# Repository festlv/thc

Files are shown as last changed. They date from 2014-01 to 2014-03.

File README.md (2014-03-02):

Homebrew plasma cutter torch height controller
--------------------------------------------------

Schematics, layout and code for a simple yet intelligent replacement for THC301d
torch height controller.

The main difference is that this one samples cutting voltage automatically
after cut is started, and then tries to keep the plasma torch at the same
height.

Beware- this has only been tested for a few hours as of now, but the results
seem to be as good as with THC301d (but setpoint is determined automatically).

License: GNU General Public License (GPL) version 3.

Author: Reinis Veips, http://wot.lv/

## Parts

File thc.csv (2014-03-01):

ref | value | footprint
C1 | 0.1uF | ~
C2 | 1uF | ~
C3 | 1uF | ~
C4 | 100uF | ~
C5 | 1uF | ~
C6 | 10uF | ~
C7 | 10uF | ~
C8 | 0.1uF | ~
C9 | 10uF | ~
C10 | 0.1uF | ~
C11 | 0.1uF | ~
C12 | 10uF | ~
CON1 | BARREL_JACK | ~
D1 | 5v1 ZENER | ~
D2 | 1N4007 | ~
D3 | 5v1 ZENER | ~
D4 | 5v1 ZENER | ~
D5 | 5v1 ZENER | ~
D6 | 5v1 ZENER | ~
D7 | 5v1 ZENER | ~
D8 | 5v1 ZENER | ~
D9 | 5v1 ZENER | ~
D10 | 5v1 ZENER | ~
D11 | 12v1 ZENER | ~
D12 | 12v1 ZENER | ~
F1 | PTC 1.1A 30V | ~
IC1 | 4N25 | DIP6
IC2 | 4N25 | DIP6
IC3 | 4N25 | DIP6
J2 | DB25 | ~
J3 | DB9 | ~
PH1 | IL300 | ~
Q1 | BC547 | TO92
R1 | 10K | ~
R2 | 10K | ~
R3 | 100R | ~
R4 | 10K | ~
R5 | 10K | ~
R6 | 10K | ~
R7 | 200R | ~
R8 | 200R | ~
R9 | 200R | ~
R10 | 200R | ~
R11 | 200R | ~
R12 | 200R | ~
R13 | 200R | ~
R14 | 200R | ~
R15 | 200R | ~
R16 | 10K | ~
R17 | 10K | ~
R18 | 10K | ~
R19 | 10K | ~
R20 | 100R | ~
R21 | 3K3 | ~
R22 | 47k | ~
R23 | 10K | ~
R24 | 400R | ~
R25 | 230R | ~
R26 | 400R | ~
R27 | 1K | ~
R28 | 1K | ~
R29 | 47k | ~
U1 | LM358
U2 | ARDUINO_MINI_PRO | ~
U3 | CNY74-4
U4 | 7805 | ~
U5 | ISOL_PWR
U6 | 74HC04 | ~
U7 | CNY74-4
U8 | ISOL_PWR | ~
U9 | LM358

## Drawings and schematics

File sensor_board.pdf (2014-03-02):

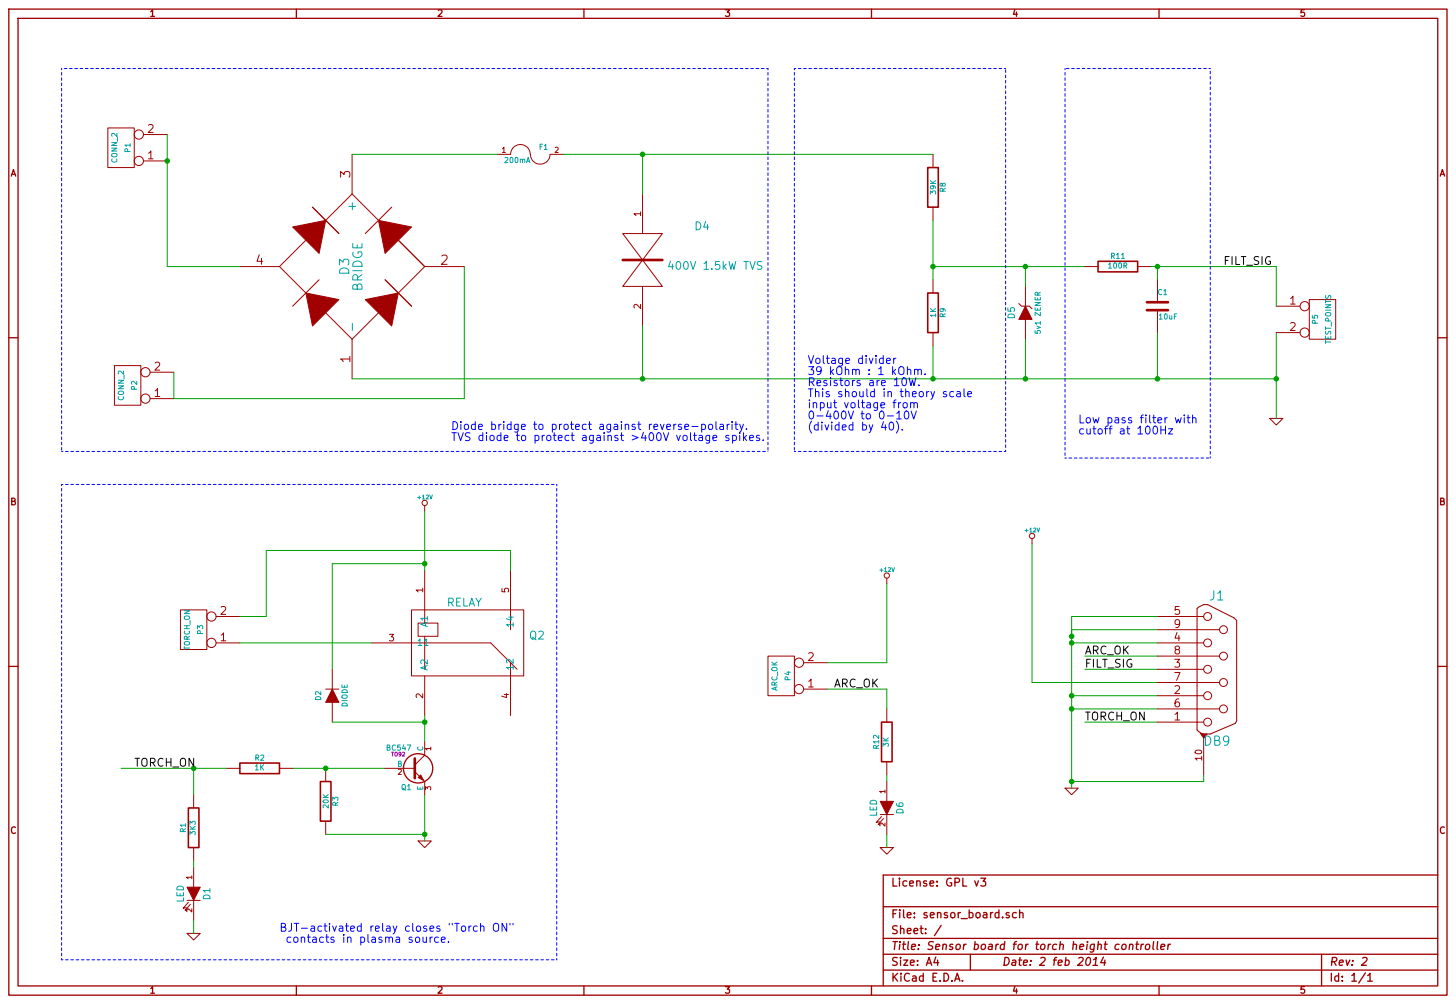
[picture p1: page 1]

Voltage divider
39 kOhm : 1 kOhm. Resistors are 10W. This should in theory scale

cutoff at 100Hz BJT-activated relay closes "Torch ON"

Diode bridge to protect against reverse-polarity.

FILT_SIG | 9 10 3

ARC_OK | 8

File: sensor_board.sch
Sheet: /
Title: Sensor board for torch height controller

contacts in plasma source.

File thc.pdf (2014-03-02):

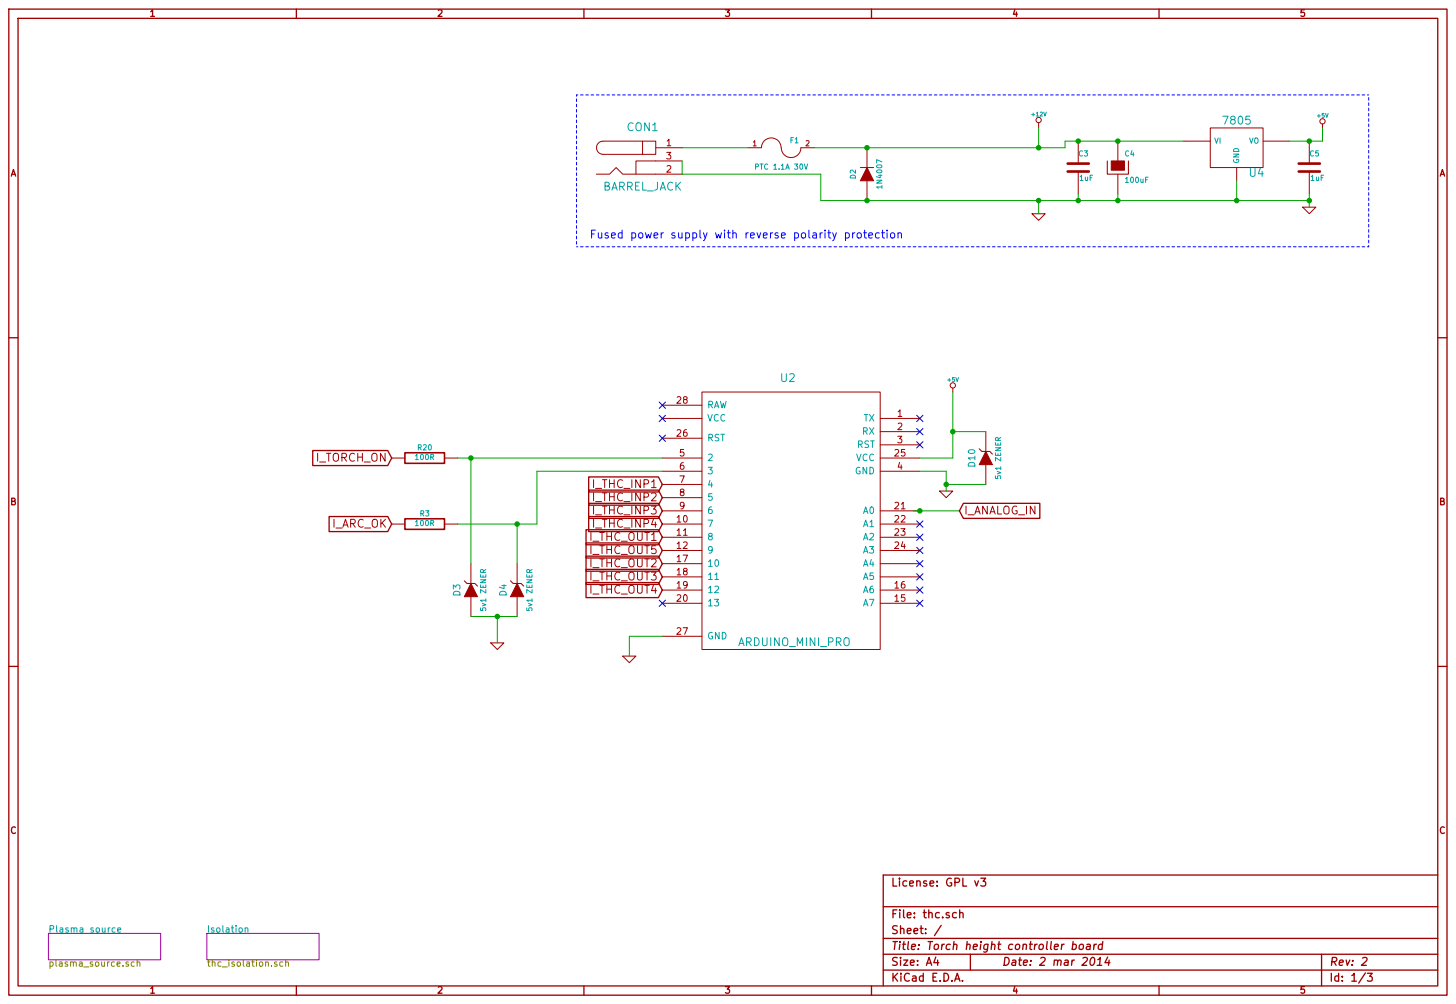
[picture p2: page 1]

Title: Torch height controller board File: thc.sch Sheet: /

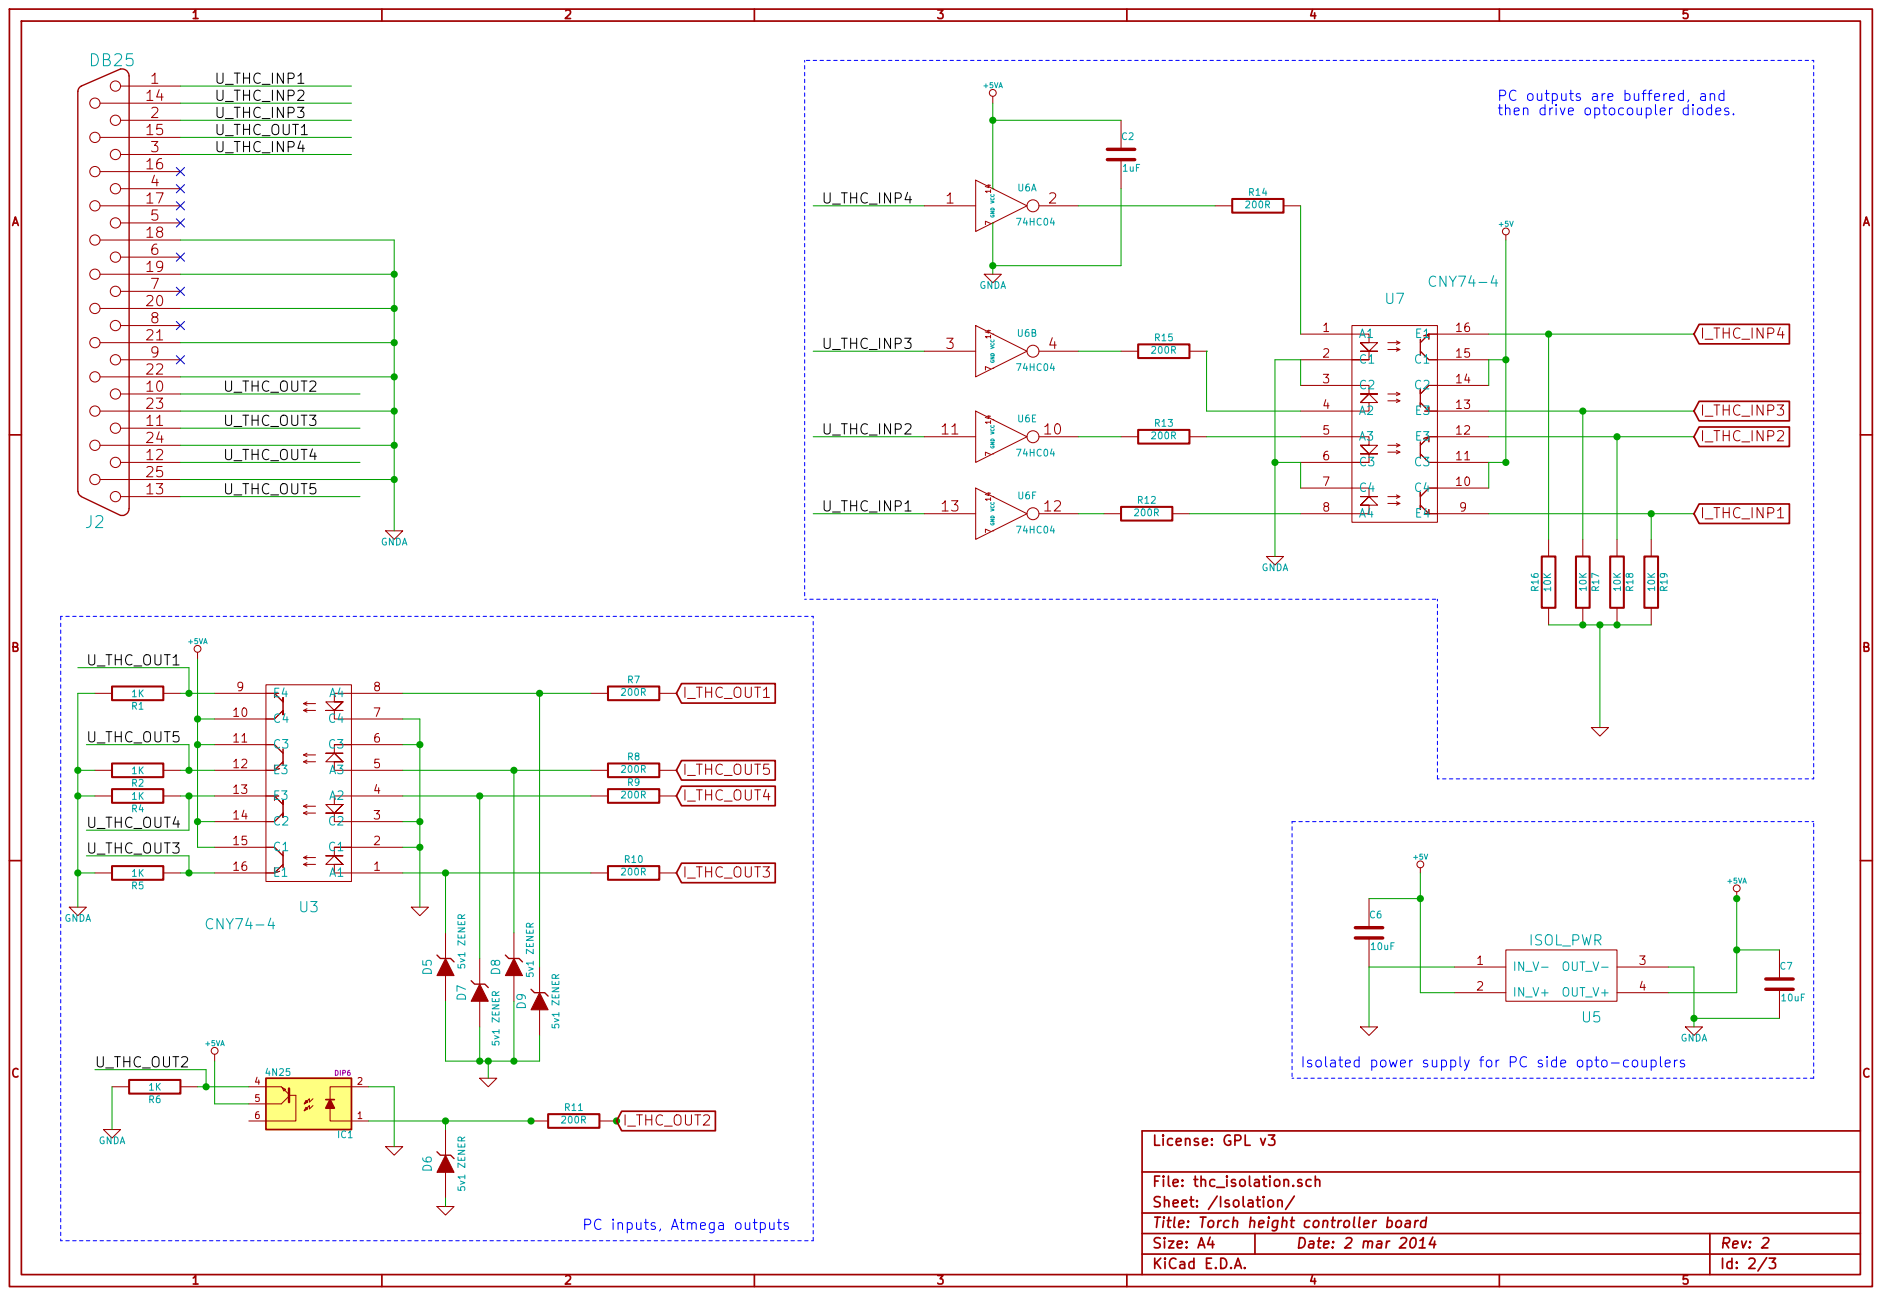
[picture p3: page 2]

PC outputs are buffered, and
then drive optocoupler diodes.

Isolated power supply for PC side opto-couplers

File: thc_isolation.sch
Sheet: /Isolation/
Title: Torch height controller board

PC inputs, Atmega outputs

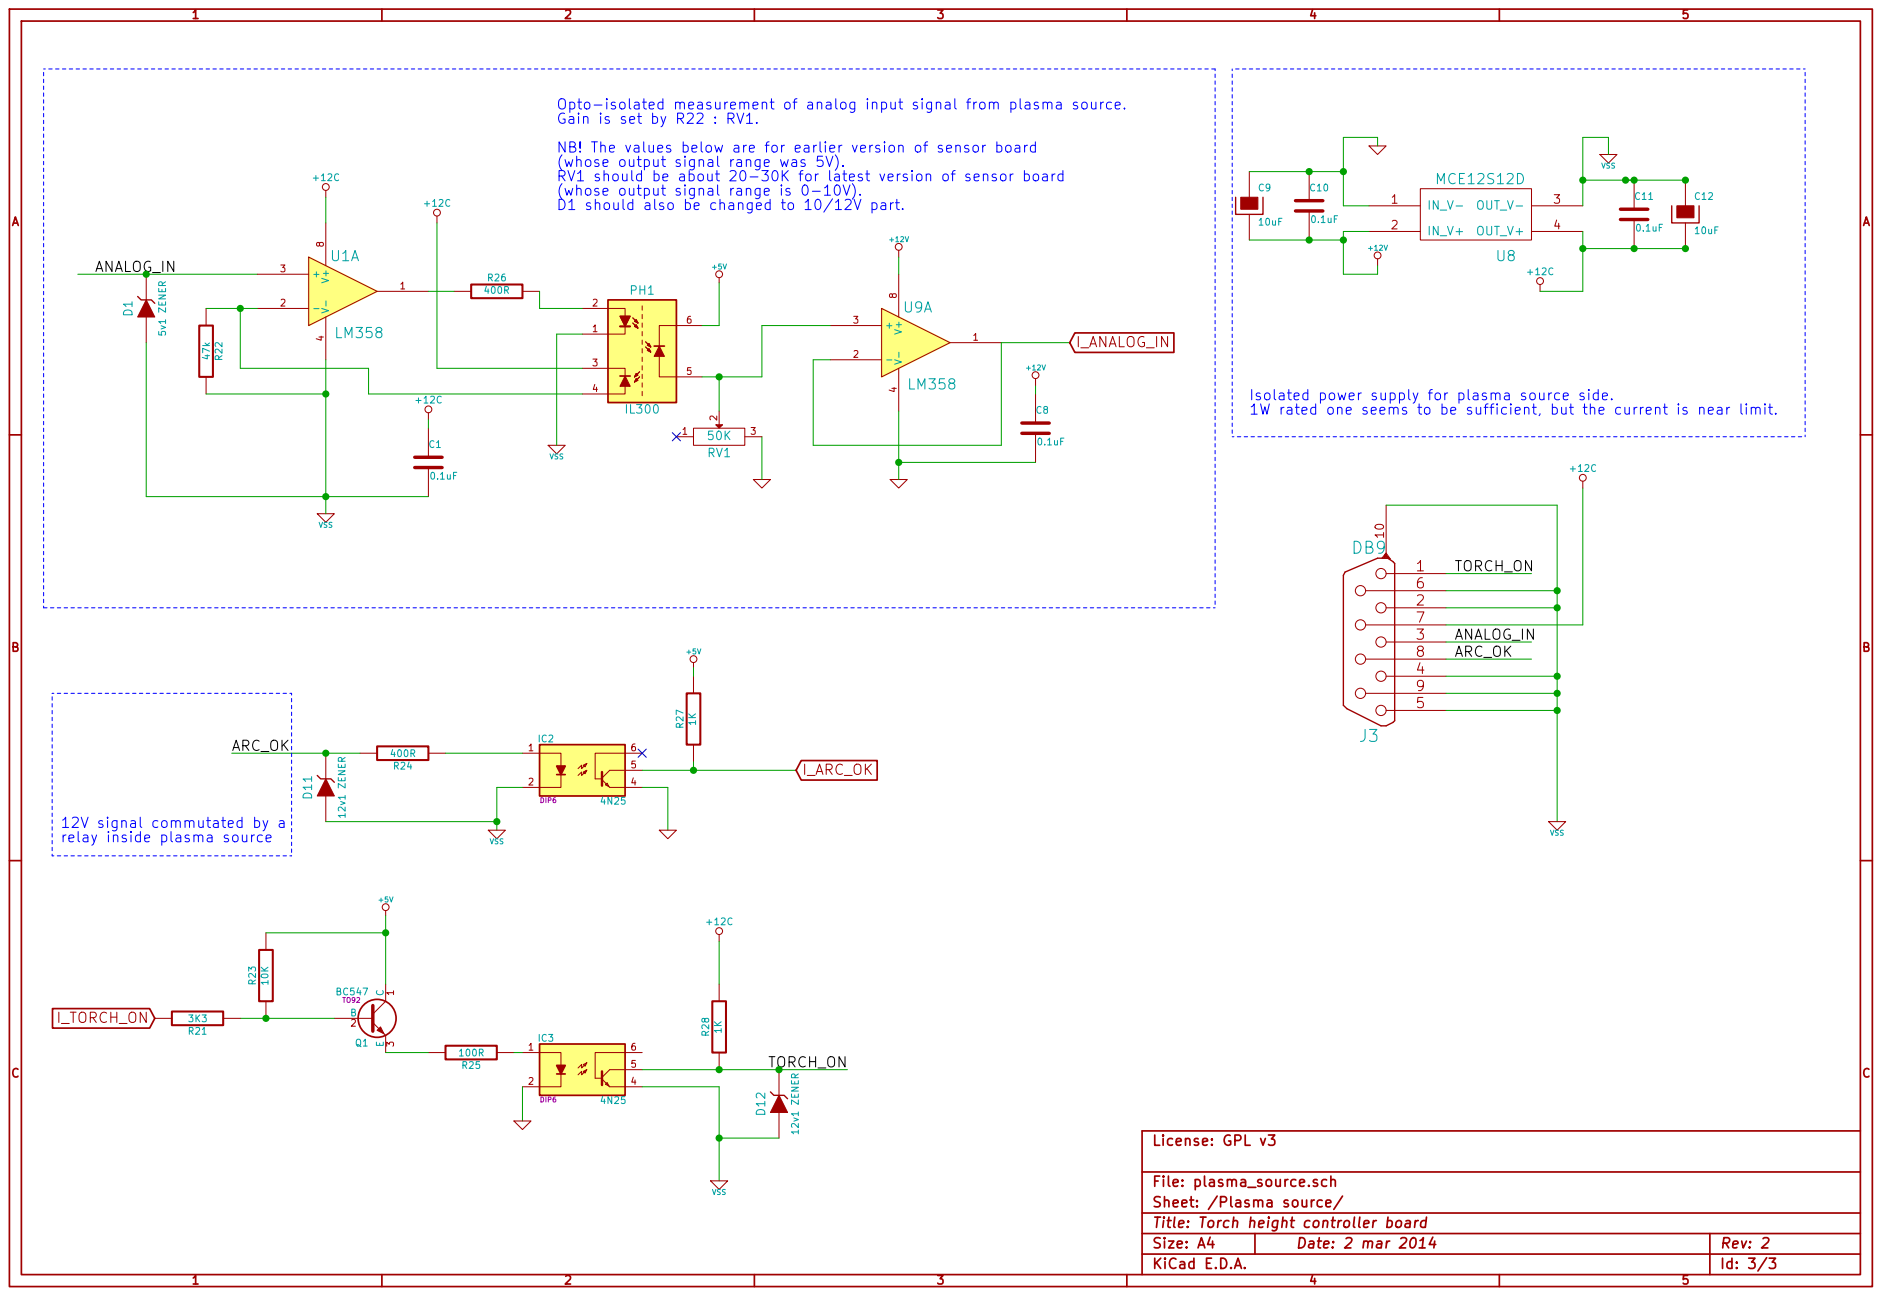
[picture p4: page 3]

50K Opto-isolated measurement of analog input signal from plasma source.
Gain is set by R22 : RV1. NB! The values below are for earlier version of sensor board (whose output signal range was 5V). RV1 should be about 20-30K for latest version of sensor board

(whose output signal range is 0-10V).
D1 should also be changed to 10/12V part.

Isolated power supply for plasma source side.
1W rated one seems to be sufficient, but the current is near limit.

12V signal commutated by a
relay inside plasma source

File: plasma_source.sch
Sheet: /Plasma source/
Title: Torch height controller board

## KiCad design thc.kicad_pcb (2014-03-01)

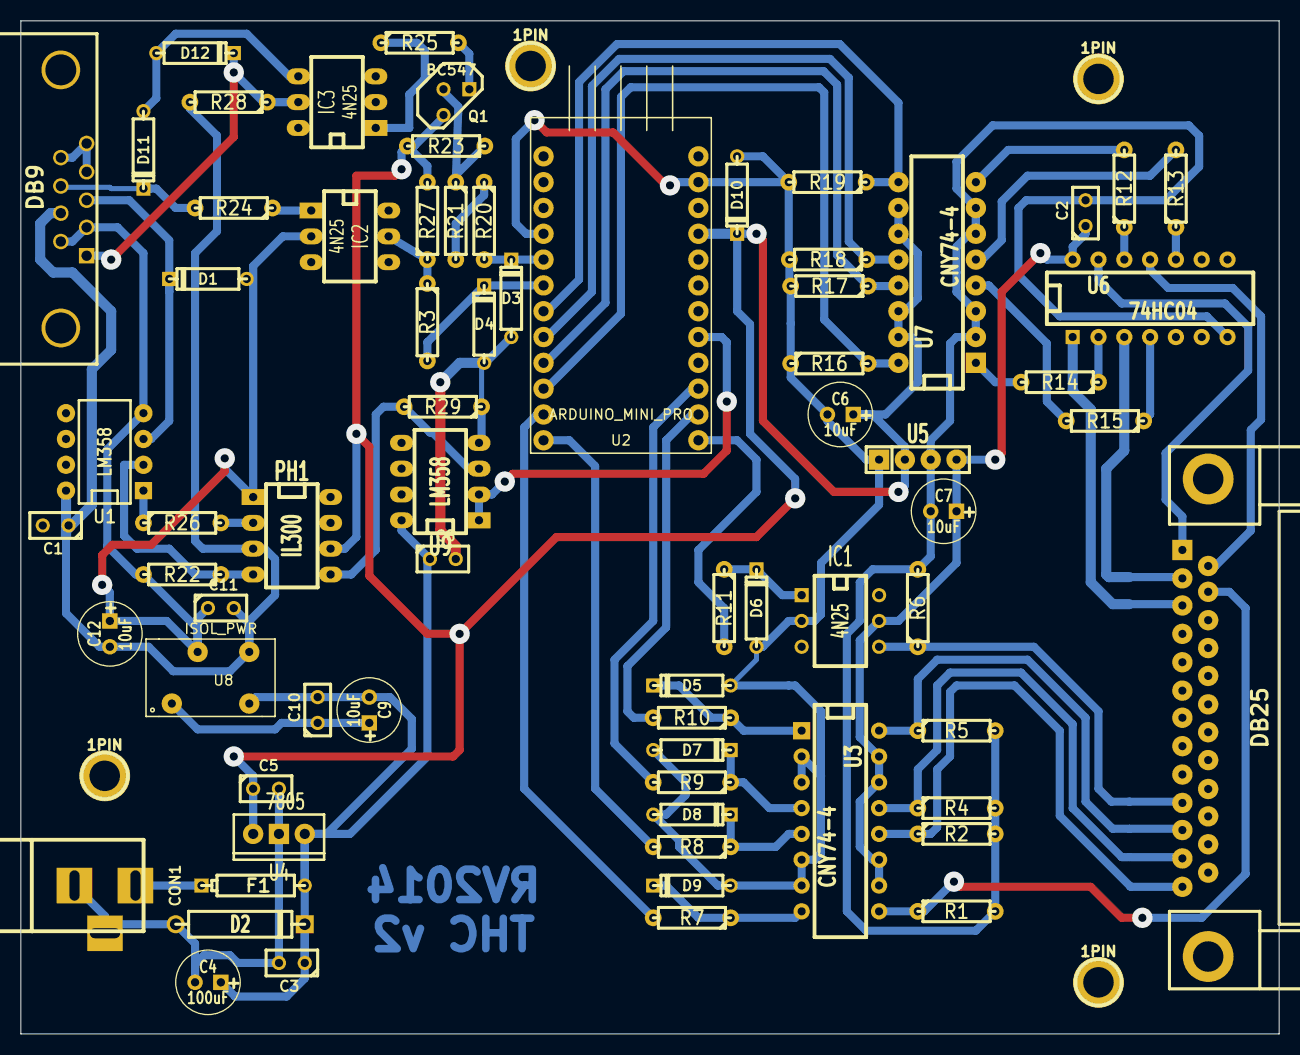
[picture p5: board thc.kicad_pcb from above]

Board: 2 copper layers, 123.8 x 99.7 mm, 75 parts (0 on the bottom side), 55 nets.

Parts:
1PIN, 1PIN#2, 1PIN#3, 1PIN#4: P***; 1pin
C1, C8, C10, C11: 0.1uF; C1
C2, C3, C5: 1uF; C1
C4: 100uF; C1V7
C6, C7, C9, C12: 10uF; C1V7
CON1: BARREL_JACK
D1, D3, D4, D5, D6, D7, D8, D9, D10: 5v1 ZENER; D3
D2: 1N4007; D5
D11, D12: 12v1 ZENER; D3
F1: PTC 1.1A 30V; CP4
IC1: 4N25; DIP-6__300
IC2, IC3: 4N25; DIP-6__300_ELL
J2: DB25; DB25FC
J3: DB9; DB9FC
PH1: IL300; DIP-8__300_ELL
Q1: BC547; TO92-EBC
R1, R2, R4, R5, R6, R16, R17, R18, R19, R23: 10K; R3-LARGE_PADS
R3, R20, R25: 100R; R3-LARGE_PADS
R7, R8, R9, R10, R11, R12, R13, R14, R15: 200R; R3-LARGE_PADS
R21: 3K3; R3-LARGE_PADS
R22, R29: 47k; R3-LARGE_PADS
R24, R26: 400R; R3-LARGE_PADS
R27, R28: 1K; R3-LARGE_PADS
U1: LM358; DIP-8__300
U2: ARDUINO_MINI_PRO; ARDUINO_MINI
U3, U7: CNY74-4; DIP-16__300
U4: 7805; LM78XXV
U5: ISOL_PWR; SIL-4
U6: 74HC04; DIP-14__300
U8: ISOL_PWR; MCE_DIP
U9: LM358; DIP-8__300_ELL

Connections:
+5V: C5.1, C6.1, D10.2, PH1.6, Q1.1, R23.2, R27.2, U2.25, U4.VO, U5.2, U7.10, U7.11, U7.14, U7.15
+5VA: C2.1, C7.1, IC1.5, U3.10, U3.11, U3.14, U3.15, U5.4, U6.14
+12C: C1.1, C11.2, C12.2, J3.7, PH1.3, R28.2, U1.8, U8.4
+12V: C3.1, C4.1, C8.1, C9.2, C10.2, D2.2, F1.2, U4.VI, U8.2, U9.8
/Isolation/U_THC_INP1: J2.1, U6.13
/Isolation/U_THC_INP2: J2.14, U6.11
/Isolation/U_THC_INP3: J2.2, U6.3
/Isolation/U_THC_INP4: J2.3, U6.1
/Isolation/U_THC_OUT1: J2.15, R1.1, U3.9
/Isolation/U_THC_OUT2: IC1.4, J2.10, R6.1
/Isolation/U_THC_OUT3: J2.11, R5.1, U3.16
/Isolation/U_THC_OUT4: J2.12, R4.1, U3.13
/Isolation/U_THC_OUT5: J2.13, R2.1, U3.12
/Plasma source/ANALOG_IN: D1.2, J3.3, U1.3
/Plasma source/ARC_OK: D11.2, J3.8, R24.2
/Plasma source/TORCH_ON: D12.2, IC3.5, J3.1, R28.1
GND: C3.2, C4.2, C5.2, C6.2, C8.2, C9.1, C10.1, CON1.2, CON1.3, D2.1, D3.1, D4.1, D5.1, D6.1, D7.1, D8.1, D9.1, D10.1, IC1.2, IC2.4, IC3.2, R16.1, R17.2, R18.2, R19.2, R29.1, U2.4, U2.27, U3.2, U3.3, U3.6, U3.7, U4.GND, U5.1, U8.1, U9.4
GNDA: C2.2, C7.2, J2.18, J2.19, J2.20, J2.21, J2.22, J2.23, J2.24, J2.25, R1.2, R2.2, R4.2, R5.2, R6.2, U5.3, U6.7, U7.2, U7.3, U7.6, U7.7
I_ANALOG_IN: U2.21, U9.1, U9.2
I_ARC_OK: IC2.5, R3.1, R27.1
I_THC_INP1: R19.1, U2.7, U7.9
I_THC_INP2: R18.1, U2.8, U7.12
I_THC_INP3: R17.1, U2.9, U7.13
I_THC_INP4: R16.2, U2.10, U7.16
I_THC_OUT1: R7.2, U2.11
I_THC_OUT2: R11.2, U2.17
I_THC_OUT3: R10.2, U2.18
I_THC_OUT4: R9.2, U2.19
I_THC_OUT5: R8.2, U2.12
I_TORCH_ON: R20.1, R21.2
unnamed: D3.2, R20.2, U2.5
unnamed: D4.2, R3.2, U2.6
unnamed: CON1.1, F1.1
unnamed: D6.2, IC1.1, R11.1
unnamed: R14.2, U7.1
unnamed: R12.2, U7.8
unnamed: R13.2, U7.5
unnamed: R15.2, U7.4
unnamed: R12.1, U6.12
unnamed: R13.1, U6.10
unnamed: R14.1, U6.2
unnamed: R15.1, U6.4
unnamed: D9.2, R7.1, U3.8
unnamed: D8.2, R8.1, U3.5
unnamed: D7.2, R9.1, U3.4
unnamed: D5.2, R10.1, U3.1
unnamed: Q1.2, R21.1, R23.1
unnamed: IC3.1, R25.1
unnamed: Q1.3, R25.2
unnamed: IC2.1, R24.1
unnamed: PH1.4, R22.1, U1.2
unnamed: R26.1, U1.1
unnamed: PH1.2, R26.2
unnamed: PH1.5, R29.2, U9.3
VSS: C1.2, C11.1, C12.1, D1.1, D11.1, D12.1, IC2.2, IC3.4, J3.2, J3.4, J3.5, J3.6, J3.9, PH1.1, R22.2, U1.4, U8.3

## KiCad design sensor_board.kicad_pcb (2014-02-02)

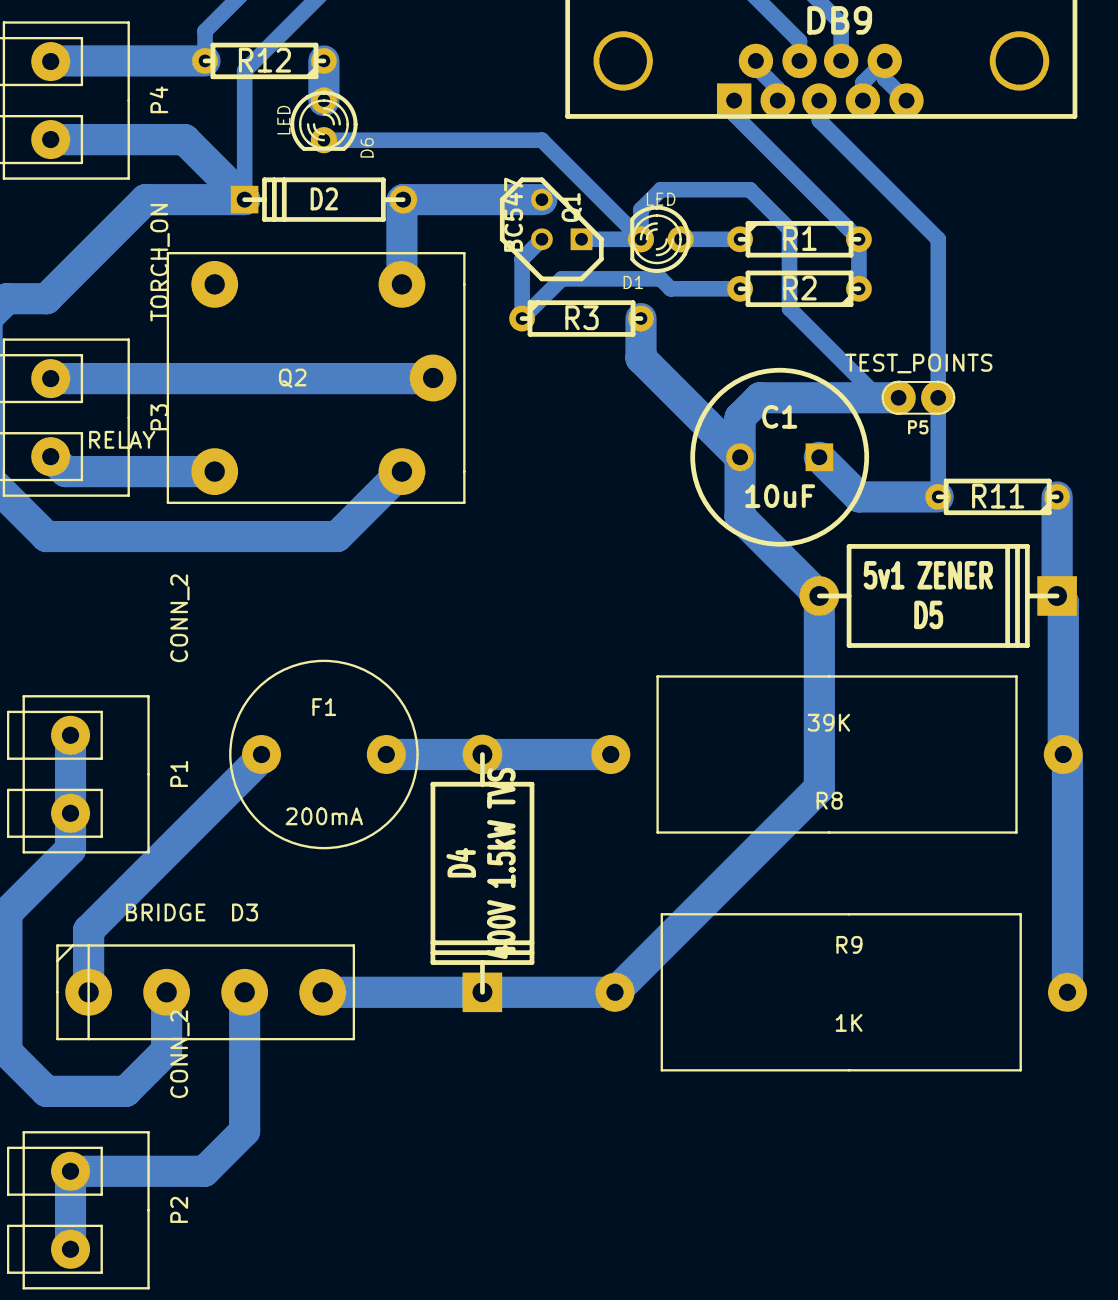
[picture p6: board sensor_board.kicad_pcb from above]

Board: 2 copper layers, 23 parts (0 on the bottom side), 16 nets.

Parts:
C1: 10uF; C2V10
D1, D6: LED; LED-3MM
D2: DIODE; D4
D3: BRIDGE
D4: 400V 1.5kW TVS; D6
D5: 5v1 ZENER; D6
F1: 200mA; ROUND_FUSE_HOLDER
J1: DB9; DB9FC
P1, P2: CONN_2; SCREW_TERM_2
P3: TORCH_ON; SCREW_TERM_2
P4: ARC_OK; SCREW_TERM_2
P5: TEST_POINTS; TEST_POINT_2PADS
Q1: BC547; TO92-CBE
Q2: RELAY; FINDER_RELAY
R1: 3K3; R3-LARGE_PADS
R2: 1K; R3-LARGE_PADS
R3: 20K; R3-LARGE_PADS
R8: 39K; R_5W_AXIAL
R9: 1K; R_5W_AXIAL
R11: 100R; R3-LARGE_PADS
R12: 3K; R3-LARGE_PADS

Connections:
+12V: D2.2, J1.7, P4.2, Q2.1
/ARC_OK: J1.8, P4.1, R12.2
/FILT_SIG: C1.1, J1.3, P5.1, R11.2
/TORCH_ON: J1.1, R1.2, R2.1
GND: C1.2, D1.2, D3.1, D4.2, D5.1, D6.2, J1.2, J1.4, J1.5, J1.6, J1.9, J1.10, P5.2, Q1.3, R3.2, R9.2
unnamed: D6.1, R12.1
unnamed: D1.1, R1.1
unnamed: D3.3, F1.1
unnamed: D5.2, R8.2, R9.1, R11.1
unnamed: D3.2, P2.1, P2.2
unnamed: D4.1, F1.2, R8.1
unnamed: Q1.2, R2.2, R3.1
unnamed: D2.1, Q1.1, Q2.2
unnamed: D3.4, P1.1, P1.2
unnamed: P3.1, Q2.3
unnamed: P3.2, Q2.5

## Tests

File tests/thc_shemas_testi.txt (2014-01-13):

13.01.2013

Testēju power daļu. Vin = 12V. Pēc LM7085 - 4.96V. Pēc optiski atdalītā barošanas bloka,
bez slodzes = 6.4V. Zem slodzes vēl netiek testēts.

*Analogās ieejas daļa*
1) 20K potenciometrs tiek pievienots starp zemi un +5V. Vidējā kāja pie FILT_SIG.
FILT_SIG vērtība: 2.05V. AMP_SIG vērtība: 2.05V
FILT_SIG vērtība: 4.96V. AMP_SIG vertība: 4.96V

TEST OK

* Torch ON signāls *
1) Pie torch on izejas tiek pieslēgta LED ar virknes rezistoru. Tiek simulēti +5V MCU ligzdas 5. pinā.
Rezultāts: LED iedegas.

TEST OK

* Arc OK signāls * 

Starp Arc OK un 12V tiek pielikts NO slēdzis.
Slēdzis atlaists, ARC_OK stāvoklis = 5V
Slēdzis nospiests, ARC_OK stavoklis = 0V

TEST OK

* U3 testi (MCU izejas, PC ieejas)

TEST OK

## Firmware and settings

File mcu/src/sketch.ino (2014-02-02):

#include <Timer.h>

#include "config.h"
#include <plasma.h>
#include <pc.h>

Timer t;

void setup()
{
    Serial.begin(57600);
    plasma_init();
    pc_init();

    t.every(250, pc_update_flag);
}
unsigned long next_millis = 0;

void loop()
{
    static unsigned long ul_tmp;
    static float f_tmp;
    plasma_step();
    pc_step();

#ifdef V_DEBUG
    ul_tmp = millis();
    f_tmp = plasma_read_voltage(); 
    Serial.print(ul_tmp);
    Serial.print('\t');
    Serial.println(f_tmp);
#endif

#ifdef DEBUG
    if (next_millis < millis()) {
        Serial.print("Plasma V:");
        Serial.println(plasma_read_voltage());
        next_millis = millis() + 1000;
        
        if (plasma_arc_ok()) {
            Serial.println("Arc OK");
        } else {
            Serial.println("Arc NOK");
        }

        pc_print_io_status();
    }
#endif 
    
    t.update();
}

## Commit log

2013-12-28 Committing changes
    [hv.sch, thc.sch]
2013-12-28 Hopefully finished sensor board, started to work on PC interface board
    [sensor_board.kicad_pcb, sensor_board.sch, thc.sch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]
2013-12-28 Increased size for some of the holes
    [sensor_board.kicad_pcb]
2013-12-29 Started work on thc board itself
    [thc.sch, thc_isolation.sch]
2013-12-29 Finished controller board
    [thc.kicad_pcb, thc.sch, thc_isolation.sch]
2014-01-13 Finalized design, produced PCB, started testing it
    [$thc.sch, drill_0.8.g, drill_1.g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]
2014-01-13 Done some more tests
    [$thc.sch, thc.kicad_pcb]
2014-01-17 Fixes completely wrong schematics and PCB layout
    [thc.kicad_pcb, thc.sch, thc_isolation.sch]
2014-01-19 Fixed sensor board schematics- it's not wise to power relay from regulator
    [sensor_board.kicad_pcb, sensor_board.sch]
2014-01-20 Fixed wrong power pin being used in Atmega
    [thc.kicad_pcb, thc_isolation.sch]
2014-01-21 Updated load resistor values in schematics
    [thc.sch, thc_isolation.sch]
2014-02-02 Committed latest revision of schematics before revamp
    [data.csv, plasma_v.csv, sensor_board.sch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]
2014-02-02 Finished sensor board, started layout of controller board
    [plasma_source.sch, sensor_board.kicad_pcb, sensor_board.sch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]
2014-02-12 Finalized new PCB
    [plasma_source.sch, thc.kicad_pcb, thc.sch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]
2014-02-17 Changed sensor board to contain less resistors
    [plasma_source.sch, thc.kicad_pcb, thc.sch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]
2014-02-17 Added Zener diodes on IO from plasma source
    [plasma_source.sch, thc.kicad_pcb, thc.sch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]
2014-02-24 Changed Q1 pulldown to pullup, fixed it's pinout
    [plasma_source.sch, thc.csv, thc.kicad_pcb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]
2014-03-01 Inverted logic for torch on relay control, removed debugging code
2014-03-02 Cleaned up schematics
    [plasma_source.sch, sensor_board.sch, thc.sch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]
2014-03-02 Removed unneccessary cruft
    [hv.sch]
